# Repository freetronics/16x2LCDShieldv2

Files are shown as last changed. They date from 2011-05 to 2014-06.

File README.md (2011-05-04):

Freetronics 16x2 LCD Shield
===========================
Copyright 2011 Freetronics Pty Ltd  
Freetronics site:  <www.freetronics.com>  
Freetronics email: <info@freetronics.com>  

A compact shield to connect an HD44780-compatible, 16x2 LCD module
and interface buttons to an Arduino or compatible such as a
Freetronics Eleven.

Features:

 * Reset button connected to Arduino reset pin.
 * 100nF smoothing capacitor.
 * Buttons for "up", "down", "left", "right", and "select" all on a
   single analog input pin.
 * Parts overlay on both the top and the bottom.

More information is available at:

  http://www.freetronics.com/16x2lcd

The "docs" folder within this repository includes a handy copy of the
schematic in PDF format and image(s) of the pcb.

INSTALLATION
------------
The design is saved as an EAGLE project. EAGLE PCB design software is
available from www.cadsoftusa.com free for non-commercial use. To use
this project download it and place the directory containing these files
into the "eagle" directory on your computer. Then open EAGLE and
navigate to Projects -> eagle -> 16x2LCDShieldv2.

DISTRIBUTION
------------
The specific terms of distribution of this project are governed by the
license referenced below.

LICENSE
-------
Licensed under the TAPR Open Hardware License (www.tapr.org/OHL).
The "license" folder within this repository also contains a copy of
this license in plain text format.

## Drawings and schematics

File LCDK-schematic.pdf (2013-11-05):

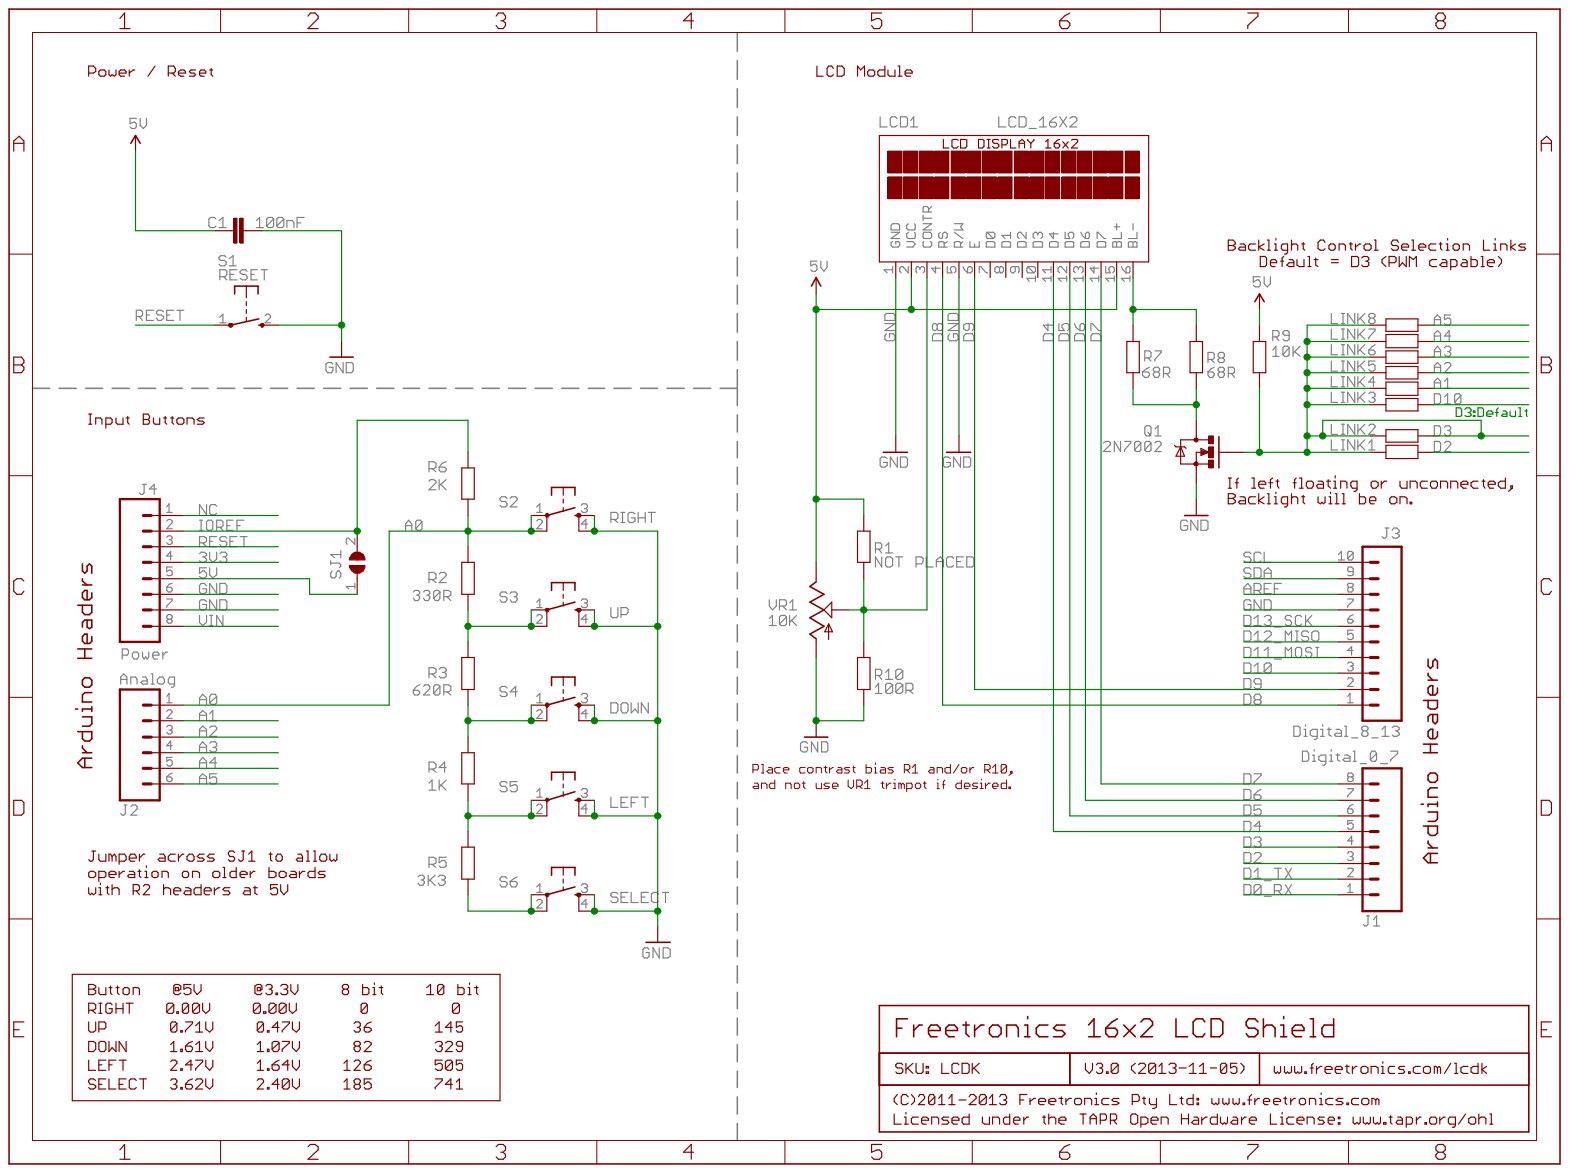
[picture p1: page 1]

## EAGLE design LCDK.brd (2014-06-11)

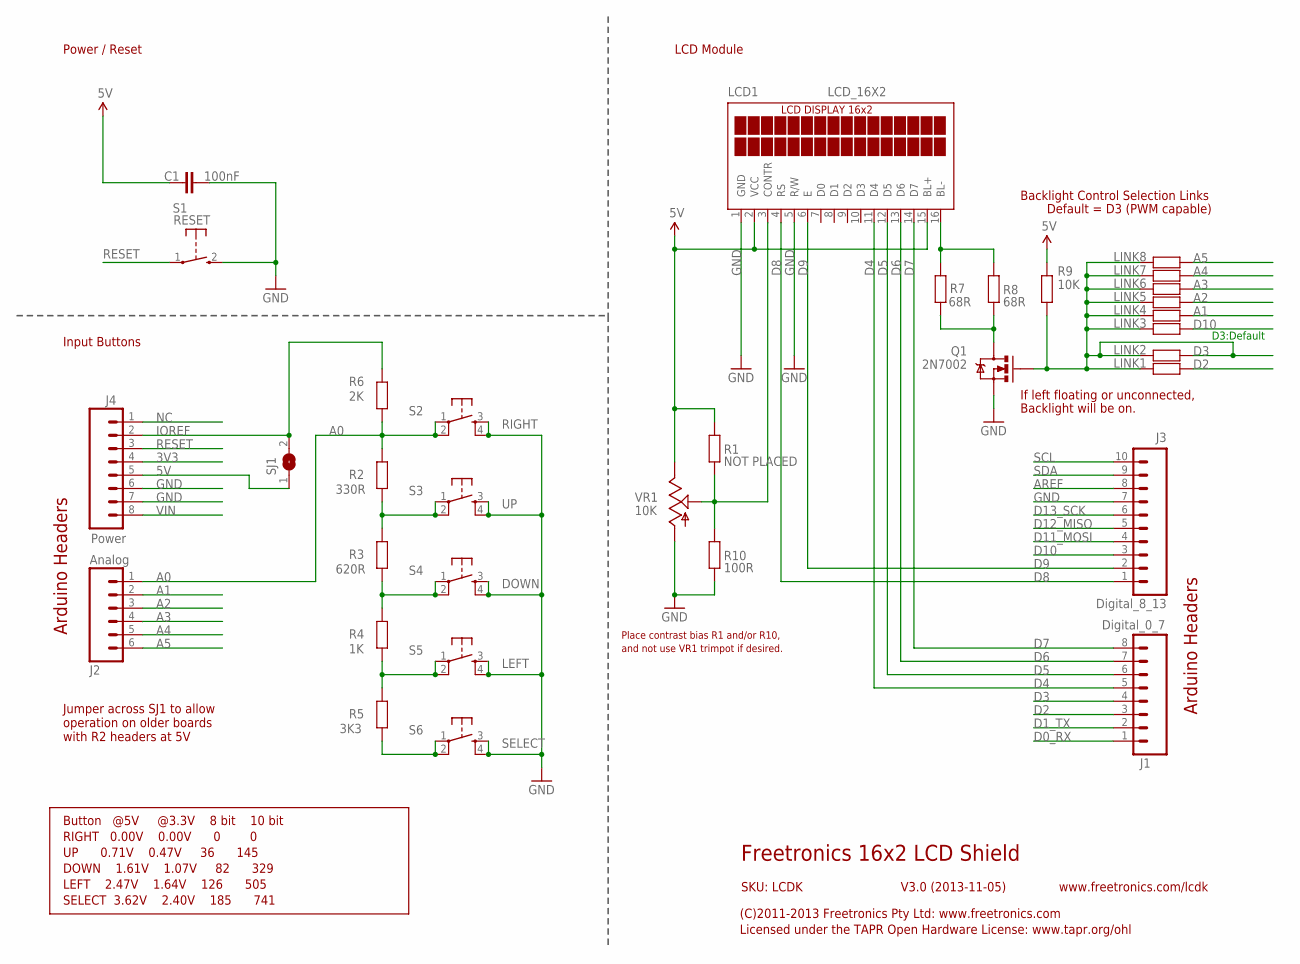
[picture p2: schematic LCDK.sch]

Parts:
C1: 100nF; 0603
J1: Digital_0_7; 1X08
J2: Analog; 1X06
J3: Digital_8_13; 1X10
J4: Power; 1X08
LCD1: LCD_16X2; LCD_16X2_REAR
LINK1, LINK2, LINK3, LINK4, LINK5, LINK6, LINK7, LINK8: RESISTOR0603; 0603
Q1: 2N7002; SOT23-3
R1: NOT PLACED; 0603
R2: 330R; 0603
R3: 620R; 0603
R4: 1K; 0603
R5: 3K3; 0603
R6: 2K; 0603
R7, R8: 68R; 0603
R9: 10K; 0603
R10: 100R; 0603
S1: RESET; TACTILE_SWITCH_SMD_2PIN_TINY
S2: RIGHT; TACTILE-PTH-4.5MM
S3: UP; TACTILE-PTH-4.5MM
S4: DOWN; TACTILE-PTH-4.5MM
S5: LEFT; TACTILE-PTH-4.5MM
S6: SELECT; TACTILE-PTH-4.5MM
SJ1: SJN; SJ
VR1: 10K; RTRIM3314J

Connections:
3V3: J4.4
5V: C1.1, J4.5, LCD1.2 (VCC), LCD1.15 (BL+), R1.2, R9.1, SJ1.1, VR1.2 (E)
A0: J2.1, R2.2, R6.1, S2.1, S2.2
A1: J2.2, LINK4.1
A2: J2.3, LINK5.1
A3: J2.4, LINK6.1
A4: J2.5, LINK7.1
A5: J2.6, LINK8.1
AREF: J3.8
D0_RX: J1.1
D1_TX: J1.2
D2: J1.3, LINK1.1
D3: J1.4, LINK1.2, LINK2.1, LINK2.2, LINK3.2, LINK4.2, LINK5.2, LINK6.2, LINK7.2, LINK8.2, Q1.1 (G), R9.2
D4: J1.5, LCD1.11 (D4)
D5: J1.6, LCD1.12 (D5)
D6: J1.7, LCD1.13 (D6)
D7: J1.8, LCD1.14 (D7)
D8: J3.1, LCD1.4 (RS)
D9: J3.2, LCD1.6 (E)
D10: J3.3, LINK3.1
D11_MOSI: J3.4
D12_MISO: J3.5
D13_SCK: J3.6
GND: C1.2, J3.7, J4.6, J4.7, LCD1.1 (GND), LCD1.5 (R/W), Q1.2 (S), R10.1, S1.2 (S), S2.3, S2.4, S3.3, S3.4, S4.3, S4.4, S5.3, S5.4, S6.3, S6.4, VR1.1 (A)
IOREF: J4.2, R6.2, SJ1.2
unnamed: LCD1.3 (CONTR), R1.1, R10.2, VR1.W (S)
unnamed: R5.1, S6.1, S6.2
unnamed: R4.1, R5.2, S5.1, S5.2
unnamed: LCD1.16 (BL-), R7.2, R8.2
unnamed: Q1.3 (D), R7.1, R8.1
unnamed: R3.1, R4.2, S4.1, S4.2
unnamed: R2.1, R3.2, S3.1, S3.2
NC: J4.1
RESET: J4.3, S1.1
SCL: J3.10
SDA: J3.9
VIN: J4.8

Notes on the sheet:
Freetronics 16x2 LCD Shield
V3.0 (2013-11-05)
SKU: LCDK
Arduino Headers
Power / Reset
LCD Module
Input Buttons
(C)2011-2013 Freetronics Pty Ltd: www.freetronics.com
Licensed under the TAPR Open Hardware License: www.tapr.org/ohl
www.freetronics.com/lcdk
Backlight Control Selection Links
Default = D3 (PWM capable)
D3:Default
Place contrast bias R1 and/or R10,
and not use VR1 trimpot if desired.
Button @5V @3.3V 8 bit 10 bit RIGHT 0.00V 0.00V 0 0 UP 0.71V 0.47V 36 145 DOWN 1.61V 1.07V 82 329 LEFT 2.47V 1.64V 126 505 SELECT 3.62V 2.40V 185 741
If left floating or unconnected,
Backlight will be on.
Jumper across SJ1 to allow operation on older boards with R2 headers at 5V

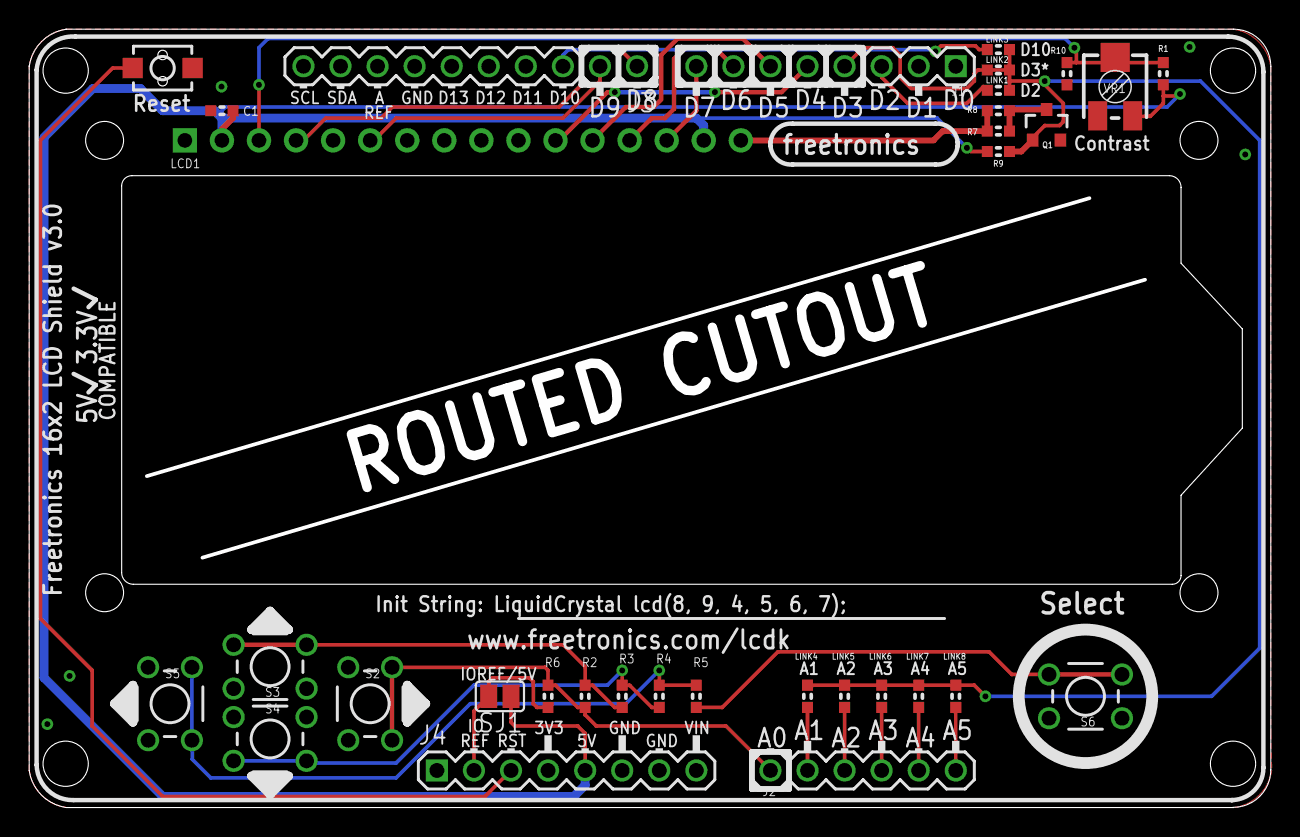
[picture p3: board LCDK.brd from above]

Board: 2 copper layers, 85.1 x 53.3 mm, 33 parts (0 on the bottom side), 26 nets.

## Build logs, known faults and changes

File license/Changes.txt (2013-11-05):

v2.1, 2013-11-05
 * Replaced SMT menu buttons with through-hole parts (Jonathan Oxer)

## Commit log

2011-03-30 Initial import of incomplete project
    [16x2LCDShieldv2.brd, 16x2LCDShieldv2.sch]
2011-04-10 v2 Initial setup - final choices to be made
    [16x2LCDShieldv2.brd, 16x2LCDShieldv2.sch]
2011-04-21 Left alignment done and checked
    [16x2LCDShieldv2.brd]
2011-04-28 Before final lookover and release
    [16x2LCDShieldv2.brd, 16x2LCDShieldv2.sch]
2011-04-29 LCD Backlight moved to D3, new smt trimpot footprint
    [16x2LCDShieldv2.brd, 16x2LCDShieldv2.sch]
2011-05-03 Final before release gerbers and inspection
    [16x2LCDShieldv2.brd, 16x2LCDShieldv2.sch]
2011-05-04 Full production
    [16x2LCDShieldv2.brd]
2011-05-18 Button ladder voltage and reading values fixed
    [16x2LCDShieldv2.sch]
2013-11-05 Converted menu buttons to through hole; renamed project files for v3.0 release
    [16x2LCDShieldv2.brd, 16x2LCDShieldv2.sch, LCDK.brd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]
2014-06-11 Add 3.3V/5V compatible label on silkscreen
    [LCDK.brd, LCDK.sch]
